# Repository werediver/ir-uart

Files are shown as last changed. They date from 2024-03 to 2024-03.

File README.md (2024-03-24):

# IR UART

This is an IR UART adapter. Its transmitter and receiver are independent, there is no automatic echo suppression. The receiver is based on [TSDP34156](http://www.vishay.com/docs/82667/tsdp341.pdf) IR receiver. The transmitter is built using [TSAL6400](https://www.vishay.com/docs/81011/tsal6400.pdf) 940 nm IR LEDs and a carrier generator based on [74HC132](https://assets.nexperia.com/documents/data-sheet/74HC_HCT132.pdf) quad-NAND CMOS gate.

The nominal transmission rate is 9600 baud. The carrier generator should be tuned to 57.6 kHz (with 6 cycles per bit it gives $57600 / 6 = 9600$ baud).

The adapter can be powered from 3.3 V or 5 V and will operate with the corresponding logic levels.

The board size is just 21x36 mm and provides 8 unconnected PTH (plated through holes) for mounting purposes. It should fit the [Pico (RP2040)](https://datasheets.raspberrypi.com/pico/pico-datasheet.pdf) board well.

| · | · |
| - | - |
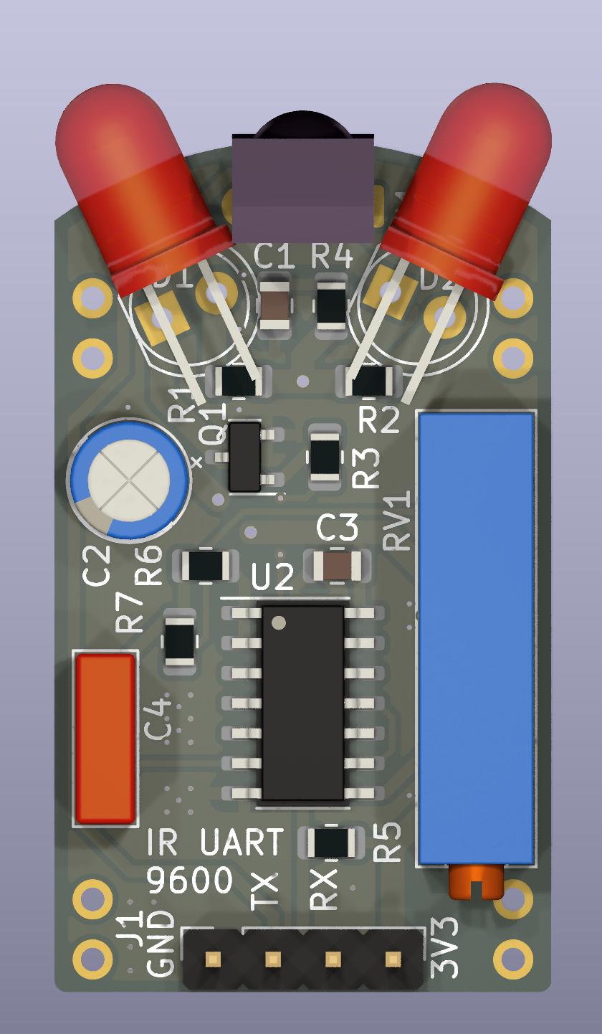
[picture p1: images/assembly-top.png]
Assembly top view
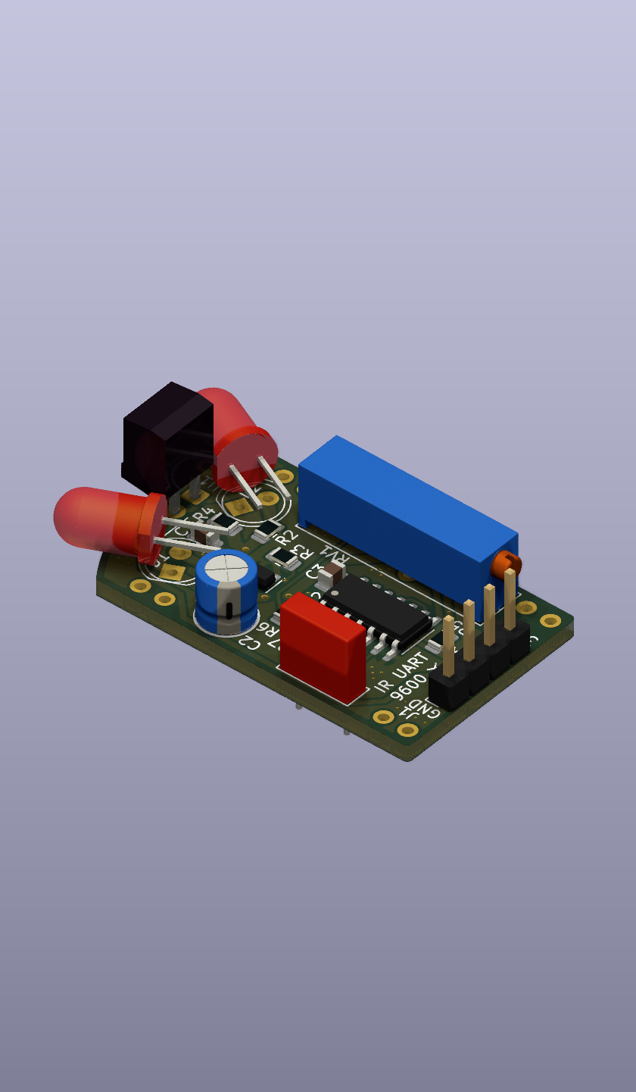
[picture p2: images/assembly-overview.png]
Assembly overview
|  |  |
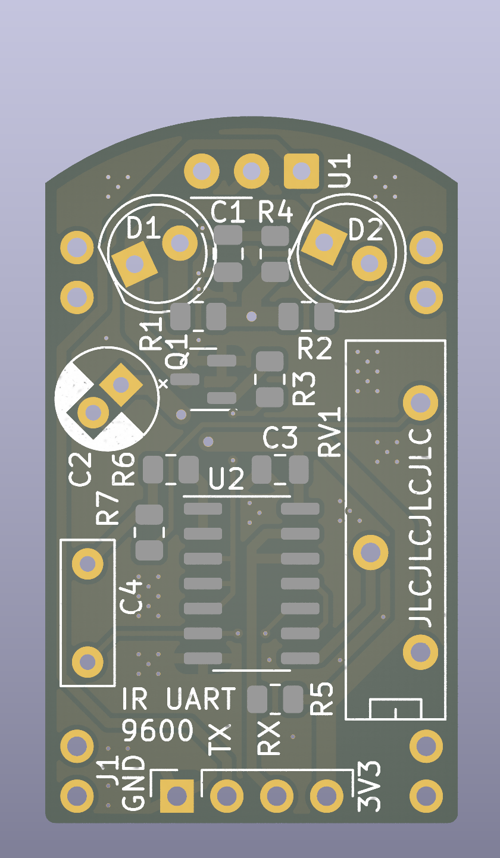
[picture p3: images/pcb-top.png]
PCB top view
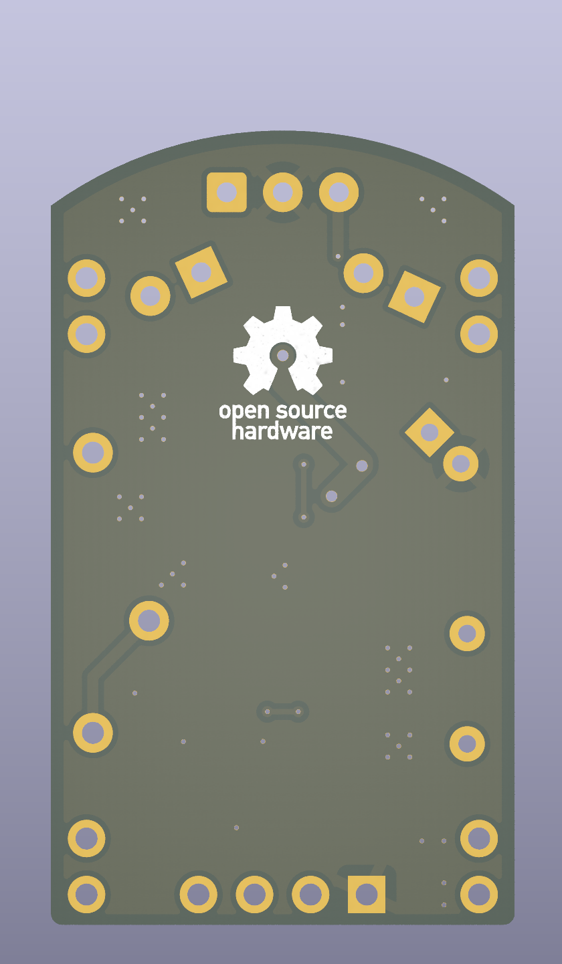
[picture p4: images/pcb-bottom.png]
PCB bottom view
|  |  |

Schematic

## Performance

With minor adjustments after the first tests, the modules work as expected transmitting and receiving 1 kHz test signal. Using the modules with UART hasn't been tested yet.

Some more photos and/or info may be found at [hackaday.io/project/195022-ir-uart](https://hackaday.io/project/195022-ir-uart).

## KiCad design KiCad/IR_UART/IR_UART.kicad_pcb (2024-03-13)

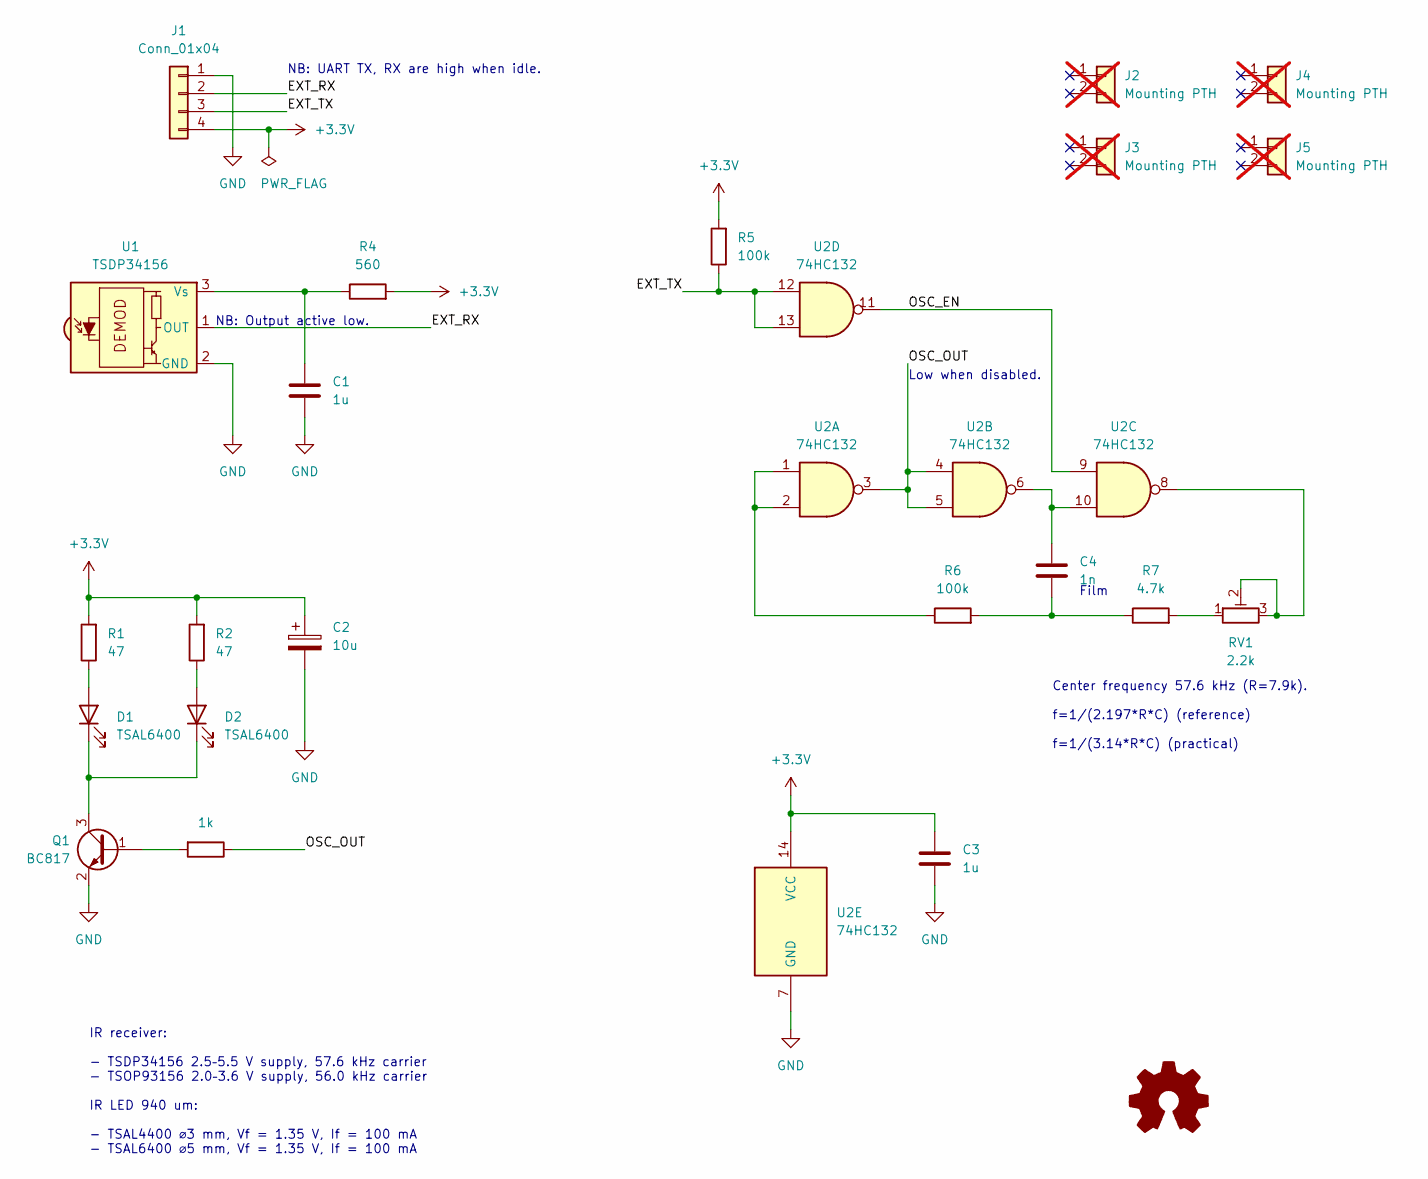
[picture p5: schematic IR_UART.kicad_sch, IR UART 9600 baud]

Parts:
C1, C3: 1u; C_0805_2012Metric
C2: 10u; CP_Radial_D5.0mm_P2.00mm
C4: 1n; C_Rect_L7.2mm_W2.5mm_P5.00mm_FKS2_FKP2_MKS2_MKP2
D1, D2: TSAL6400; LED_D5.0mm
J1: Conn_01x04; PinHeader_1x04_P2.54mm_Vertical
J2, J3, J4, J5: Mounting PTH; PinHeader_1x02_P2.54mm_Vertical; not fitted
Q1: BC817; SOT-23
R1, R2: 47; R_0805_2012Metric
R3: 1k; R_0805_2012Metric
R4: 560; R_0805_2012Metric
R5, R6: 100k; R_0805_2012Metric
R7: 4.7k; R_0805_2012Metric
RV1: 2.2k; Potentiometer_Bourns_3006P_Horizontal
SYM1: Logo_Open_Hardware_Small; OSHW-Logo_5.7x6mm_SilkScreen
U1: TSDP34156; Vishay_MOLD-3Pin
U2: 74HC132; SO-14_3.9x8.65mm_P1.27mm

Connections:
+3.3V: C2.1, C3.1, J1.4, R1.2, R2.2, R4.2, R5.2, U2.14 (VCC)
/EXT_RX: J1.2, U1.1 (OUT)
/EXT_TX: J1.3, R5.1, U2.12, U2.13
/OSC_EN: U2.9, U2.11
/OSC_OUT: R3.1, U2.3, U2.4, U2.5
GND: C1.2, C2.2, C3.2, J1.1, Q1.2 (E), U1.2 (GND), U2.7 (GND)
unnamed: C4.1, U2.6, U2.10
unnamed: C4.2, R6.2, R7.1
unnamed: D1.2 (A), R1.1
unnamed: D1.1 (K), D2.1 (K), Q1.3 (C)
unnamed: D2.2 (A), R2.1
unnamed: Q1.1 (B), R3.2
unnamed: R6.1, U2.1, U2.2
unnamed: R7.2, RV1.1
unnamed: RV1.2, RV1.3, U2.8
unnamed: C1.1, R4.1, U1.3 (Vs)

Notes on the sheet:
NB: Output active low.
Film
Low when disabled.
NB: UART TX, RX are high when idle.
Center frequency 57.6 kHz (R=7.9k). f=1/(2.197*R*C) (reference) f=1/(3.14*R*C) (practical)
IR receiver: - TSDP34156 2.5–5.5 V supply, 57.6 kHz carrier - TSOP93156 2.0–3.6 V supply, 56.0 kHz carrier IR LED 940 um: - TSAL4400 ⌀3 mm, Vf = 1.35 V, If = 100 mA - TSAL6400 ⌀5 mm, Vf = 1.35 V, If = 100 mA

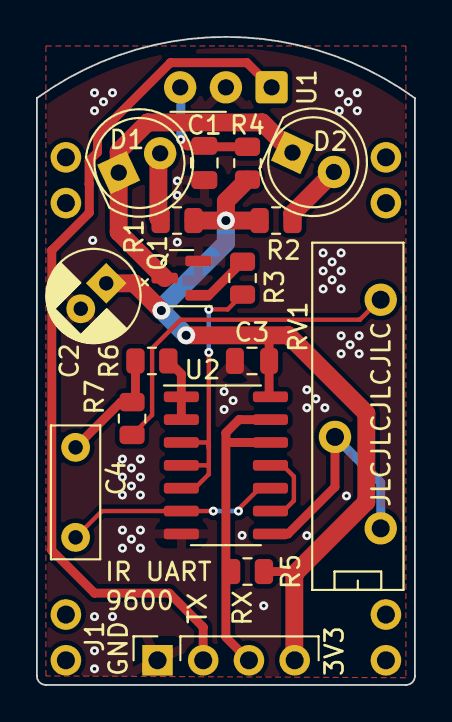
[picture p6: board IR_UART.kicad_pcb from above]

Board: 2 copper layers, 21.0 x 36.0 mm, 23 parts (1 on the bottom side), 16 nets.

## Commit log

2024-02-24 The initial revision
    [IR_UART.kicad_pcb, IR_UART.kicad_sch]
2024-03-13 Update the schematic and the PCB
    - Use 4.7k resistor instead of 6.8k in the timing circuit
    - Minor changes to the board, mainly aroung the 4-pin connector
    [IR_UART.kicad_pcb, IR_UART.kicad_sch]
2024-03-24 Update the schematic to specify IR receiver supply filter to be 100R 4.7uF to fix the slow fronts of the received signal.
    [IR_UART.kicad_sch]
